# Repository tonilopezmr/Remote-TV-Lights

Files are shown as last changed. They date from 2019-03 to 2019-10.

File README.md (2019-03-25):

# Remote-TV-Lights
Turn on/off TV Leds with remote control.

Board supplied by USB from TV which turns on/off DC 12v LEDs by NPN Transistor TIP41C remotely using any remote control. 

### Usage
You need to configure it for add allowed infrared signals clicking to the button, then the led starts blinking, that means the board it is waiting to get an infrared signal from your remote control, then press to the remote control button you selected for turn on/off TV lights, once you have pressed the button and the led stop blinking the board has been configured, just press the button to check your light is turning on/off.

### PCB 

Top layout
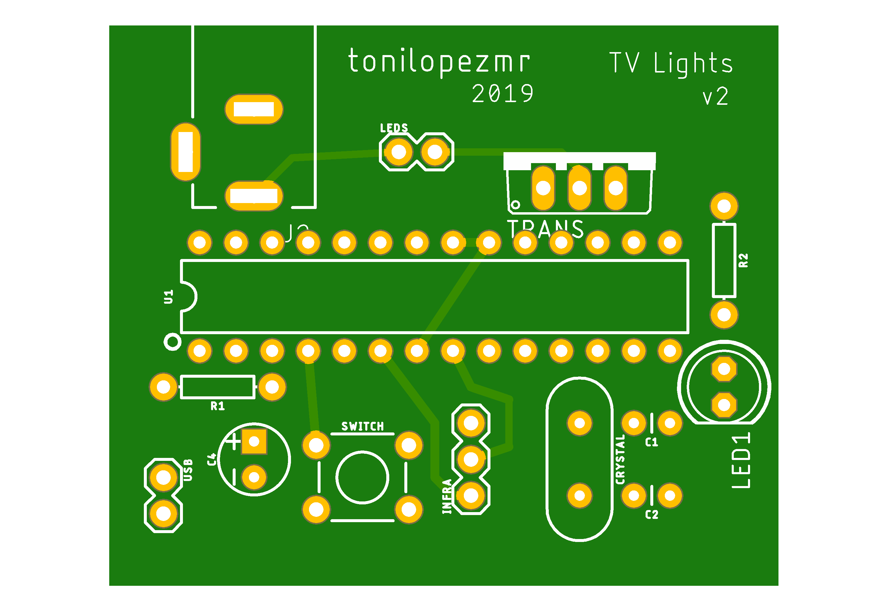
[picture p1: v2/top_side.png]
Board top layout


Bottom layout
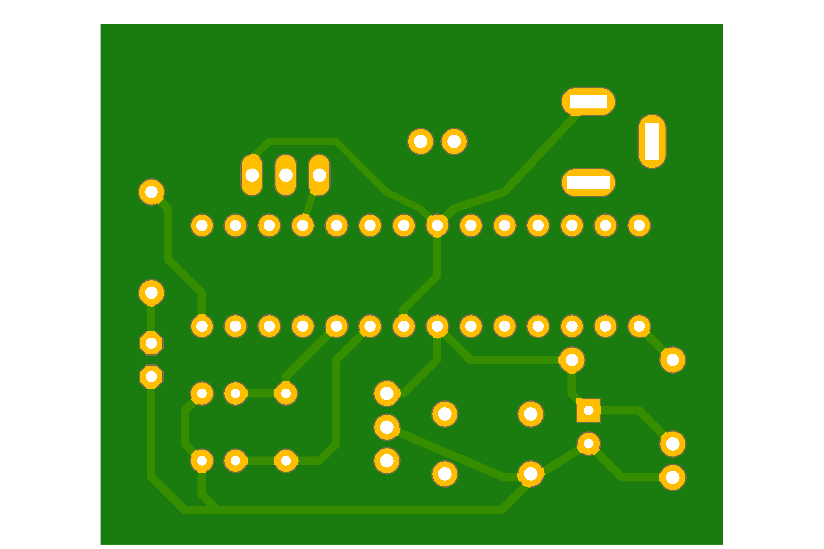
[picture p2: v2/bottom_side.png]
Board bottom layou


## Open Hardware

Hardware designs (schematics and CAD) files are licensed under the [Creative Commons Attribution-ShareAlike 3.0 Unported License](http://creativecommons.org/licenses/by-sa/3.0/) and follow the terms of the [OSHW (Open-source hardware) Statement of Principles 1.0.](http://freedomdefined.org/OSHW)

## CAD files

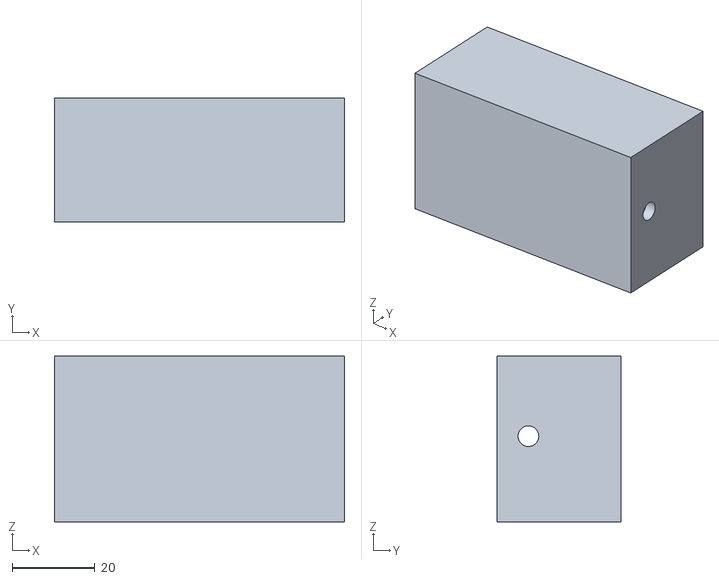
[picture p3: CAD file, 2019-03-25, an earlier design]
v1/enclosure.stl
70.0 x 30.0 x 40.0

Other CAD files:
v1/enclosure.f3d

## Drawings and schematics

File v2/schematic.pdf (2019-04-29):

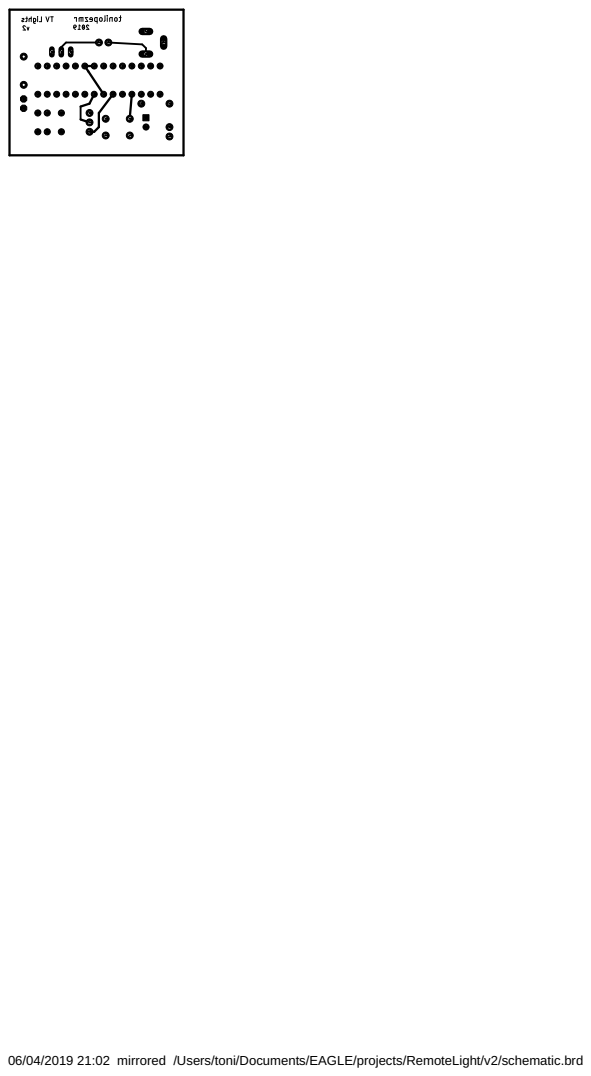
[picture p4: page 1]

06/04/2019 21:02 mirrored /Users/toni/Documents/EAGLE/projects/RemoteLight/v2/schematic.brd

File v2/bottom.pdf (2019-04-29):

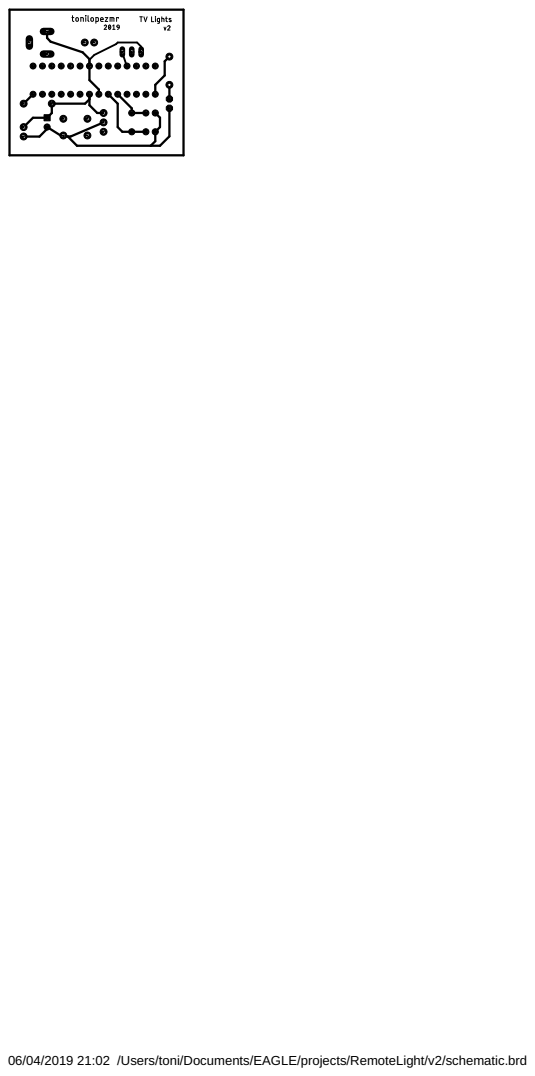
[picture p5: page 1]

06/04/2019 21:02 /Users/toni/Documents/EAGLE/projects/RemoteLight/v2/schematic.brd

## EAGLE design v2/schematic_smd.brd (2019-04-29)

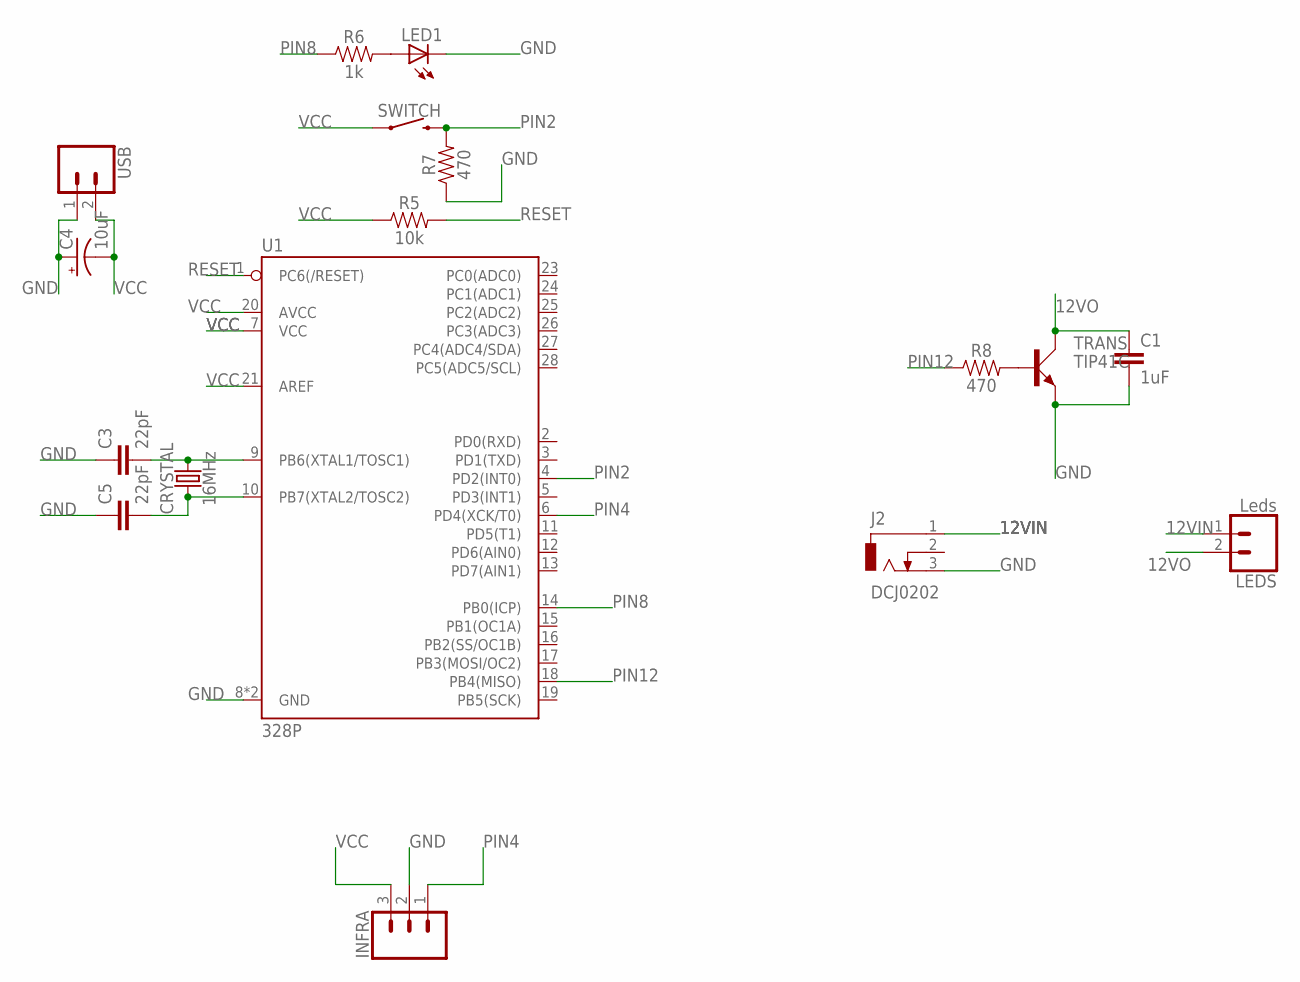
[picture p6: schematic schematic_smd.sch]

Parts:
C1: 1uF; 1206
C3, C5: 22pF; 1206
C4: 10uF; CPOL-RADIAL-2.5MM-5MM
CRYSTAL: 16MHz; HC49US
INFRA: 455-1750-1-ND; 1X03
J2: DCJ0202
LED1: LED5MM
LEDS: Leds; JST-2-PTH-KIT
R5: 10k; 0805
R6: 1k; 1206
R7, R8: 470; 1206
SWITCH: MOMENTARY-SWITCH-SPST-PTH-6.0MM; TACTILE_SWITCH_PTH_6.0MM
TRANS: TIP41C; TO220AV
U1: 328P; DIP28
USB: CONN_02JST-PTH-2-KIT; JST-2-PTH-KIT

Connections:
12VIN: J2.1, LEDS.1
12VO: C1.1, LEDS.2, TRANS.C
GND: C1.2, C3.1, C4.1 (+), C5.1, INFRA.2, J2.3, LED1.K (C), R7.1, TRANS.E, U1.8 (GND), U1.22 (GND), USB.1
unnamed: C5.2, CRYSTAL.1, U1.10 (PB7(XTAL2/TOSC2))
unnamed: C3.2, CRYSTAL.2, U1.9 (PB6(XTAL1/TOSC1))
unnamed: LED1.A, R6.2
unnamed: R8.2, TRANS.B
PIN2: R7.2, SWITCH.3 (2), U1.4 (PD2(INT0))
PIN4: INFRA.1, U1.6 (PD4(XCK/T0))
PIN8: R6.1, U1.14 (PB0(ICP))
PIN12: R8.1, U1.18 (PB4(MISO))
RESET: R5.2, U1.1 (PC6(/RESET))
VCC: C4.2 (-), INFRA.3, R5.1, SWITCH.1, U1.7 (VCC), U1.20 (AVCC), U1.21 (AREF), USB.2

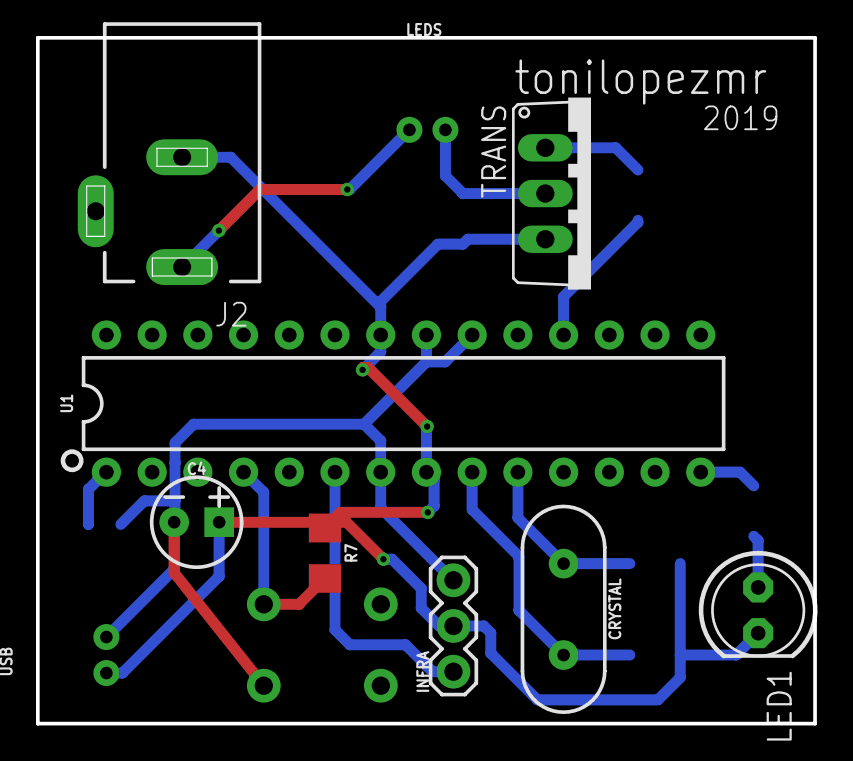
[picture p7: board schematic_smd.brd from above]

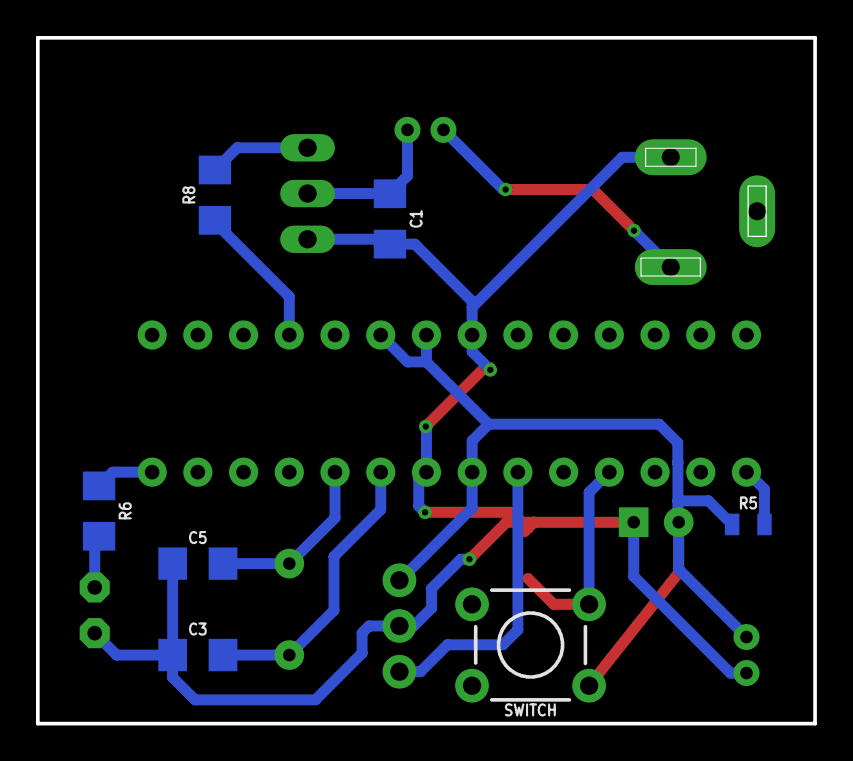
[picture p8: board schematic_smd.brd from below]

Board: 2 copper layers, 43.2 x 38.1 mm, 17 parts (7 on the bottom side), 13 nets.

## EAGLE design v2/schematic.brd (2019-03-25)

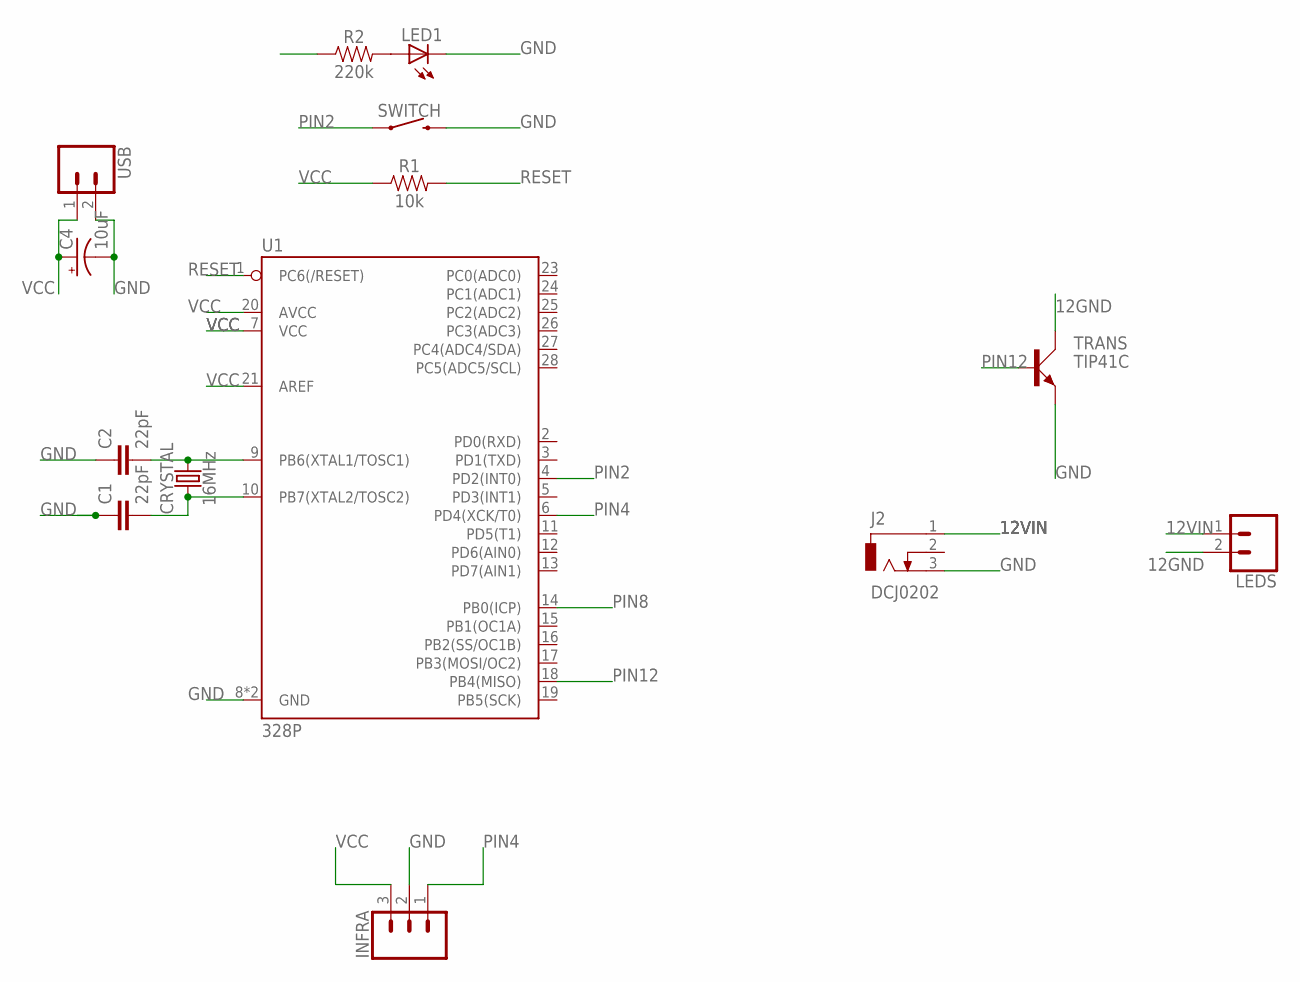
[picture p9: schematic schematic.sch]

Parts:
C1, C2: 22pF; CAP-PTH-2.54
C4: 10uF; CPOL-RADIAL-2.5MM-5MM
CRYSTAL: 16MHz; HC49US
INFRA: 455-1750-1-ND; 1X03
J2: DCJ0202
LED1: LED5MM
LEDS: CONN_02; 1X02
R1: 10k; AXIAL-0.3
R2: 220k; AXIAL-0.3
SWITCH: MOMENTARY-SWITCH-SPST-PTH-6.0MM; TACTILE_SWITCH_PTH_6.0MM
TRANS: TIP41C; TO220AV
U1: 328P; DIP28
USB: CONN_02; 1X02

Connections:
12GND: LEDS.2, TRANS.C
12VIN: J2.1, LEDS.1
GND: C1.1, C2.1, C4.2 (-), INFRA.2, J2.3, LED1.K (C), SWITCH.3 (2), TRANS.E, U1.8 (GND), U1.22 (GND), USB.2
unnamed: C1.2, CRYSTAL.1, U1.10 (PB7(XTAL2/TOSC2))
unnamed: C2.2, CRYSTAL.2, U1.9 (PB6(XTAL1/TOSC1))
unnamed: LED1.A, R2.P$2 (2)
PIN2: SWITCH.1, U1.4 (PD2(INT0))
PIN4: INFRA.1, U1.6 (PD4(XCK/T0))
PIN8: R2.P$1 (1), U1.14 (PB0(ICP))
PIN12: TRANS.B, U1.18 (PB4(MISO))
RESET: R1.P$2 (2), U1.1 (PC6(/RESET))
VCC: C4.1 (+), INFRA.3, R1.P$1 (1), U1.7 (VCC), U1.20 (AVCC), U1.21 (AREF), USB.1

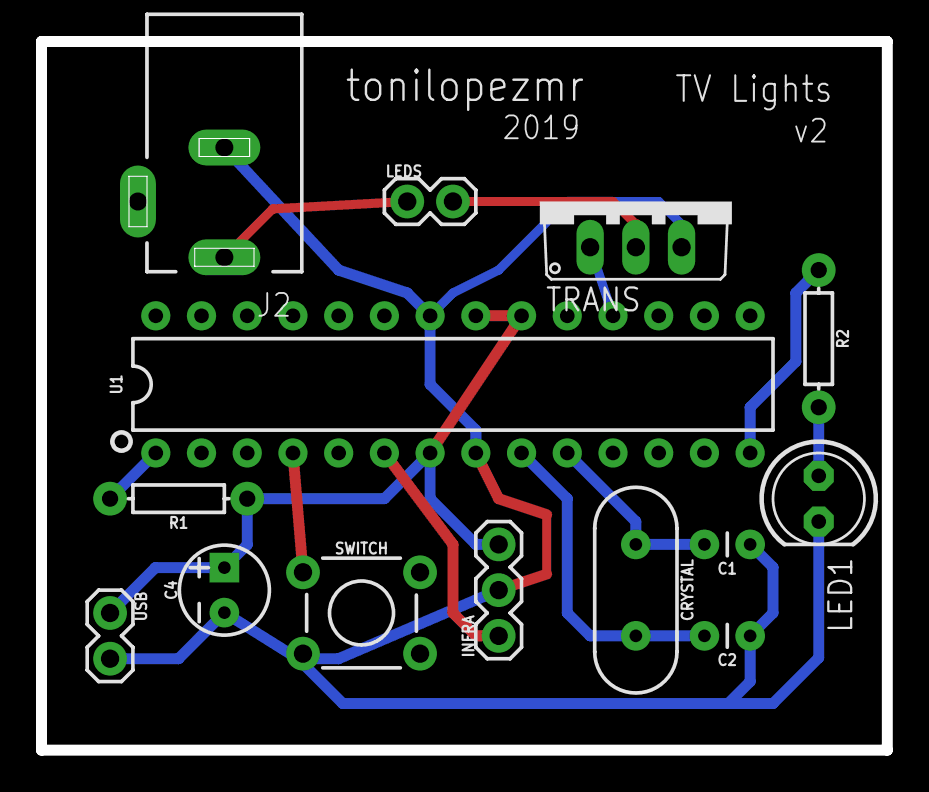
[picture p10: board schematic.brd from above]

Board: 2 copper layers, 47.0 x 39.4 mm, 14 parts (0 on the bottom side), 12 nets.

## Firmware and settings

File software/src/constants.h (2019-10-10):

#include <JustWifi.h>

#define TRANSISTOR_PIN           2
#define LED_PIN                  14
#define BUTTON_PIN               4
#define IRIN                     5

#define IR_DEBOUNCE              500
#define LED_BLINK_TIME           1000
#define LED_BLINK_SUPPORT        false

#define DEFAULT_SSID             "default-wifi" 
#define DEFAULT_WIFI_PASSWORD    "default-pass"

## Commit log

2019-03-25 Add project v2
    [schematic.brd, schematic.sch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]
2019-03-25 Create manufacturer folder
    [copper_bottom.gbr, copper_top.gbr, gerber_job.gbrjob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]
2019-03-25 V2 project
    [schematic.brd, schematic.sch]
2019-03-25 Add v1 enclosure
    [enclosure.f3d, enclosure.stl]
2019-04-29 Added v2 smd board
    [schematic_smd.brd, schematic_smd.sch]
2019-10-12 Add board name and relay button

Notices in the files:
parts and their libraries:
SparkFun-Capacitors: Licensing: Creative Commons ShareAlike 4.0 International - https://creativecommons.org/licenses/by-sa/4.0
